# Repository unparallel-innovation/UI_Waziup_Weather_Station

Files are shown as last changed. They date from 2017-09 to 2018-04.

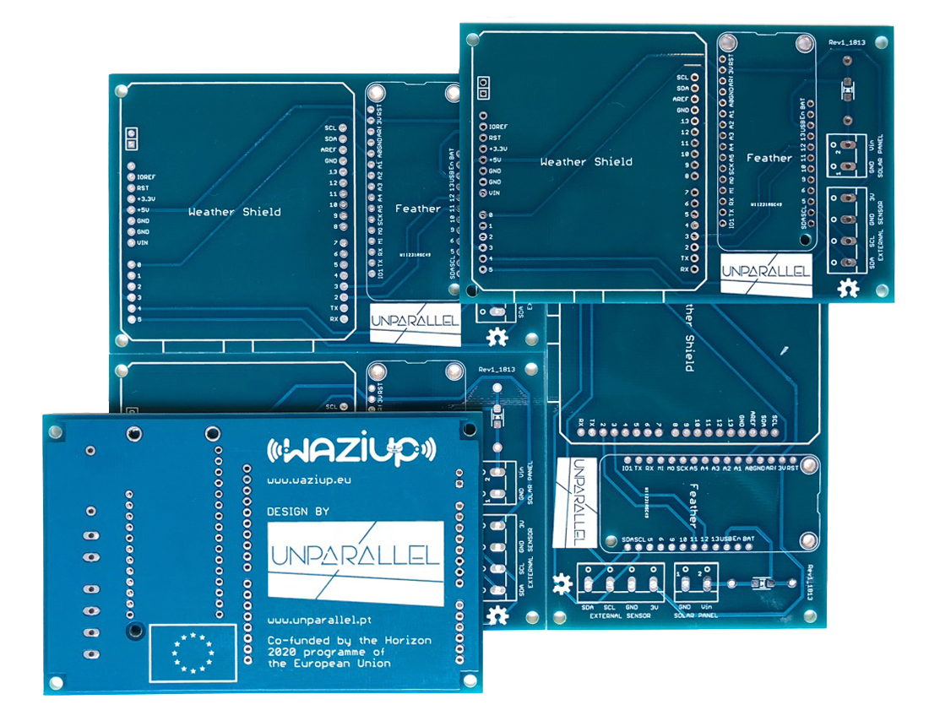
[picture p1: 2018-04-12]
Proto_Feather_with_Weather/proto_Feather_with_Weather_0v20.png

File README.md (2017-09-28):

# LoRa Weather Station for Waziup project - by UNPARALLEL Innovation, Lda

This repository provide all information related to the LoRa Weather Station. 
This Weather Station uses LoRa communication technology. It describes the creation of a vigilant weather supervision, composed by multi-tech sensors as part of the IoT sensor node with LoRa network integration. This work was done in the context of Waziup Research Project, which has received funding from the European Union’s H2020 Programme for research, technological development and demonstration under grant agreement No 687607.

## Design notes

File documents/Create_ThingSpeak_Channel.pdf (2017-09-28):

## Create the ThingSpeak channel

To be able to send weather data from the LoRa Weather Station to a ThingSpeak channel it is need to take a few steps.

1) First of all login on the platform¹ with the following email and password:

Email: noitedoinvestigador@unparallel.pt
Password: NoiteInvestigador2017

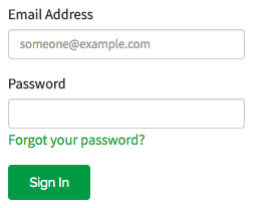
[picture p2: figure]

Figure 1 – Login on the ThingSpeak platform.

After insert, the email and the password click in the green “Sign In” button.

2) After sign in, go on the top bar “Channels”, “My channels” and then click in “New Channel” like in the following figure

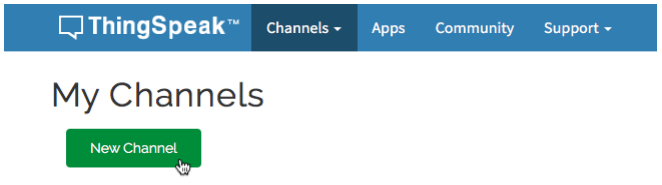
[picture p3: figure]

Figure 2 – Create a new channel in ThingSpeak.

1 https://thingspeak.com/

3) Fill “Name” and “Description” boxes with information about the new ThingSpeak.

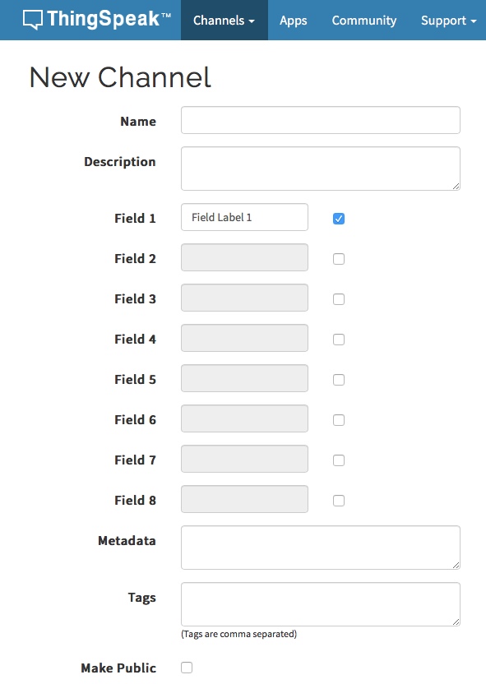
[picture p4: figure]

Figure 3 - Information about the new ThingSpeak channel.

4) Check the field boxes to be able to give the following names:
- Filed 1: “Temperature”
- Field 2: ”Humidity”
- Field 3: “Pressure”
- Field 4: “Wind Direction”
- Field 5: “Wind Speed”
- Filed 6: “Wind Gust”
- Field 7: “Amount of Rain”
- Filed 8: “Battery Voltage”
5) Check the “Make Public” button.

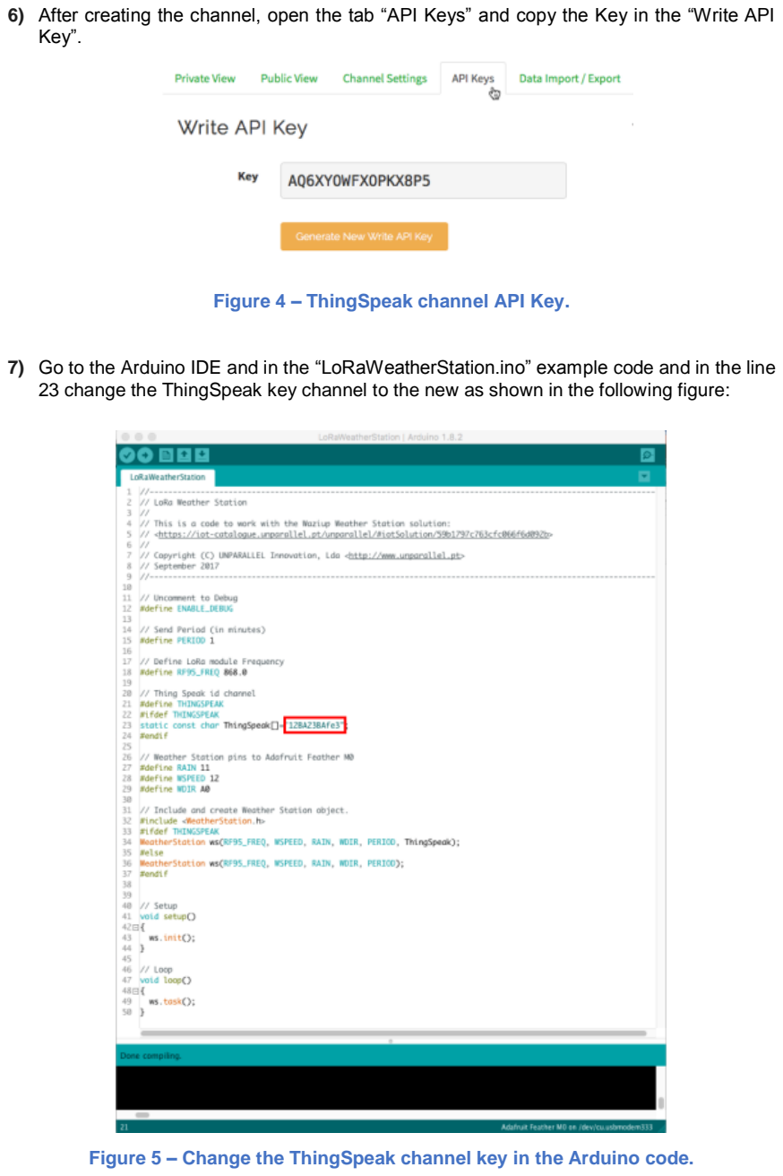
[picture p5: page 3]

6) After creating the channel, open the tab “API Keys” and copy the Key in the “Write API Key”.

Figure 4 – ThingSpeak channel API Key.

7) Go to the Arduino IDE and in the “LoRaWeatherStation.ino” example code and in the line 23 change the ThingSpeak key channel to the new as shown in the following figure:

Figure 5 – Change the ThingSpeak channel key in the Arduino code.

8) The following examples shows the result, for a short period of time, from Weather Station in the ThingSpeak Cloud platform.

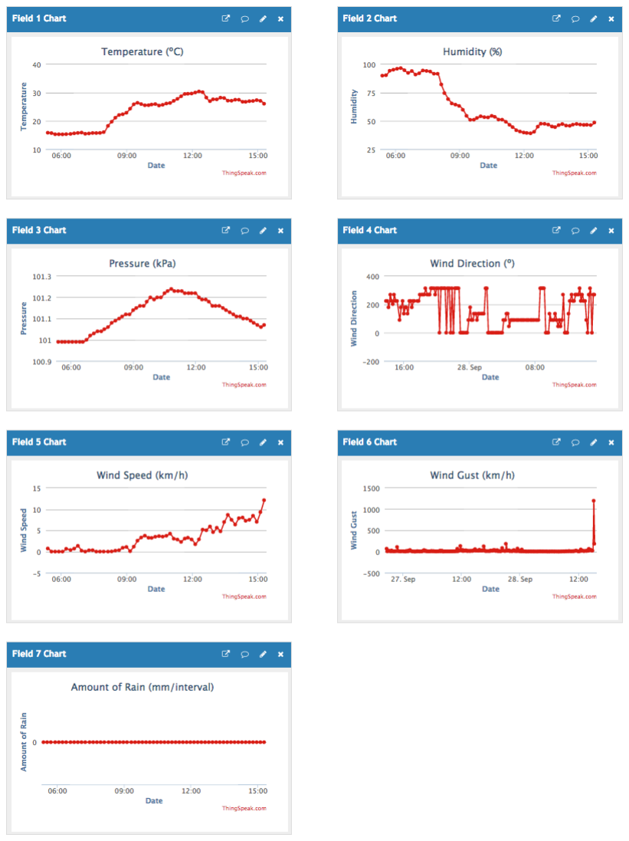
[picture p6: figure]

Figure 6 - Represented the ThingSpeak Cloud platform.

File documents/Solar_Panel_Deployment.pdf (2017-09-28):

# Solar Panel Deployment

Simple guide to deploy a Solar Panel.

Responsible Editor: Unparallel Innovation, Lda Contributors:
Document Reference: | Solar Panel Deployment
Distribution: | Public
Version: | 1.0
Date: | 28 September 2017

Table of Contents

List of Figures

# 1 . Deployment

Solar Panels are devices that consist in a set of solar cells capable to convert light into energy and if the amount of light that reach a cell increase, more energy will be produced and will increase the solar panel efficiency.

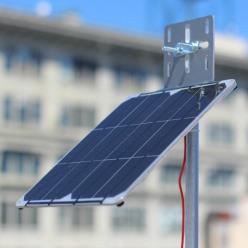
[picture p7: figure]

Figure 1 - Example of a Solar Panel deployment.

In order to have maximum possible efficiency, the panel must be pointed directly at the light source. The panel positioning is the most important because if implemented with wrong direction and slope will affect the solar panel efficiency.

For each location is extremely necessary and is a good policy to set a direction and slope that receive the maximum incident of sunlight to increase the efficiency of the solar panel under ideal conditions. Protecting them from excessive exposure to water/vapors is also necessary because this can oxidize the surface of the solar panel and reduce its performance.

The position of the Sun relative to the Earth has determine the ideal angle. It is recommended that the solar panel be deployed to pointed to “South” if the intended location is in the Northern Hemisphere or to pointed to “North” if the location is in the Southern Hemisphere as shown in the Figure 2.

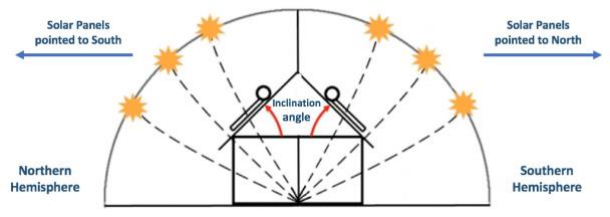
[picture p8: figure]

Figure 2 - Direction to pointed Solar Panels for location in Northern/Southern hemisphere.

However, it is necessary to analyze the location because there may be shadows and obstacles that reduce the efficiency of the solar panel. In a careful deployment, is necessary to specify the worst conditions and is recommended to use an external source of information to aid in the implementation. The selected location was Lisbon which is located in the Northern hemisphere. In this case the solar panel needs to be pointed to South as represented in the Figure 3.

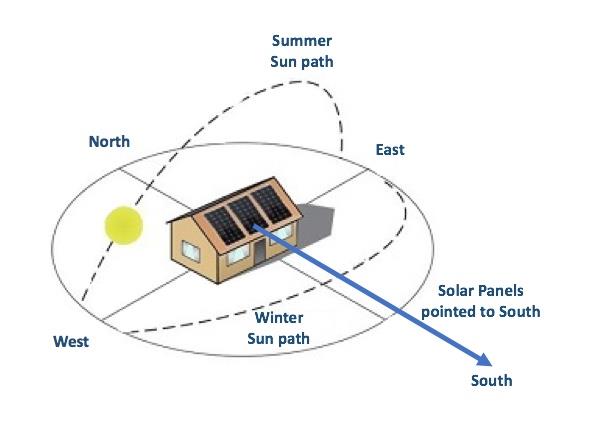
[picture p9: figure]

Figure 3 - Solar Panel deployment pointed to South.

Using a website¹
to simulate the recommended slopes, was possible to find the ideal angles per month to have maximum efficiency of the solar panel. To optimize the solar panels, is necessary adjust the slope to the values that are recommended for each of the months as shown in the Figure 4.

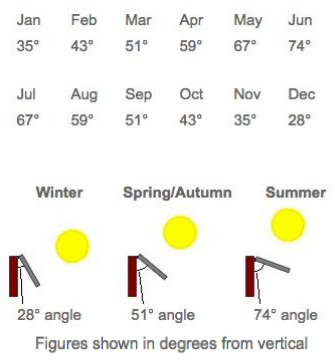
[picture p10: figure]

Figure 4 - Optimum Inclination of Solar Panels by Month and seasons.

It is also possible to adjust for the three recommended seasons of the year. In Lisbon, the recommended values for Winter is a slope of 28º, for Spring and Autumn an inclination of 51º and in the Summer the slope of 71º.

With this platform is possible to get the recommended values but other sources with different types of information can also be used to optimize the solar panels.

1 http://www.solarelectricityhandbook.com/solar-angle-calculator.aspx

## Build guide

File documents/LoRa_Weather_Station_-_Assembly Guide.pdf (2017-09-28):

WAZIUP: Co-funded by the Horizon 2020 Framework Programme of the European Union

www.waziup.eu

# Open Innovation Platform for IoT-Big data in Sub-Sahara Africa

# Grant Agreement Nº 687607

## Agriculture MVP Waziup Weather Station – Assembly Guide

Responsible Editor: Unparallel Innovation, Lda

Contributors:

Document Reference: | LoRa Weather Station - Assembly Guide
Distribution: | Public
Version: | 1.0
Date: | 28 September 2017

Project Nº 687607

TABLE OF CONTENTS

LIST OF FIGURES

Figure 1 – Components chosen | 6
Figure 2 – Female Header pins in Feather | 7
Figure 3 – uFL SMT Antenna Connector in Feather | 7
Figure 4 – Female header pins and RJ11 connectors in Weather Shield | 8
Figure 5 – Connect the 868MHz Antenna in Feather | 8
Figure 6 – Different SMA and RP-SMA connectors | 9
Figure 7 – Weather Shield power connection | 10
Figure 8 – Weather Shield internal sensors pin connection | 11

Figure 9 – Power and internal sensors connection between Feather and Weather Shield. ..11

Figure 10 – Pin Connection between Feather, External sensor and Weather Shield | 12
Figure 11 – Weather Meters and respective Rain and Wind connections | 13
Figure 12 – Connect the Battery in the Feather | 13
Figure 13 – Correct Diode connection | 14
Figure 14 – Solar Panel connection | 14
Figure 15 – Add Adafruit Boards to Arduino IDE | 15
Figure 16 – Install Adafruit Boards in Arduino IDE | 16
Figure 17 – Install Weather Station library by the "Add. ZIP Library" | 17
Figure 18 – Define the USB port | 17
Figure 19 – Upload the software | 18
Figure 20 – Place Weather Station in a box | 19
Figure 21 – Place external sensor outside the box | 19
Figure 22 – LoRa Weather Station prototype | 20

## LIST OF TABLES

Table 1 – Pin Connection to power the Weather Shield | 9
Table 2 – Weather Shield internal sensors pin connection | 10
Table 3 – Pin Connection between Feather, External sensor and Weather Shield | 12

## 1. INTRODUCTION

This document describe the development of a Waziup Weather Station using low-cost hardware that together will communicates with Waziup LoRa Gateway. In order to develop this solution, multi-technology sensors were used as part of the IoT sensor node with LoRa network integration.

The challenge was to develop an easy-to-deploy solution capable of acquire data from the surrounding area and then making it available to the Waziup Cloud Platform. This solution uses a several components that are easily bought on the market and can be potentially replaced by equivalent models.

This work was done in the context of Waziup Research Project, which has received funding from the European Union’s H2020 Programme for research, technological development and demonstration under grant agreement No 687607.

## 2. COMPONENTS

The objective is to develop a low-cost and sustainable solution capable of reading real-time data typical of a Weather Station, using different sensors, and capable of communicating via LoRa.

The components chosen was:

- Adafruit Feather M0 with RFM95 LoRa Radio
- Sparkfun Weather Shield
- Weather Meters
- 4,5 dBi 868-900 SMAM-RP Antenna
- uFL SMT Antenna Connector
- RP-SMA to uFL/u.FL/IPX/IPEX RF Adapter Cable
- 2x RJ11 6-Pin Connector
- 36-pin 0.1" Female header - pack of 5
- Adafruit AM2315 Sensor
- 1.5W Solar Panel 81x137
- Lithium-Ion Battery - 3.7v 2200mAh
- Schottky Rectifying Diode

The use of all this material allowed the development of the "LoRa Weather Station" solution that cost less than 200€ and is available on the IoT-Catalogue platform through the following link¹

In the following Figure 1 are represented the respective materials mentioned above.

1 https://iot-catalogue.unparallel.pt/unparallel/#iotSolution/59b1797c763cfc066f6d092b

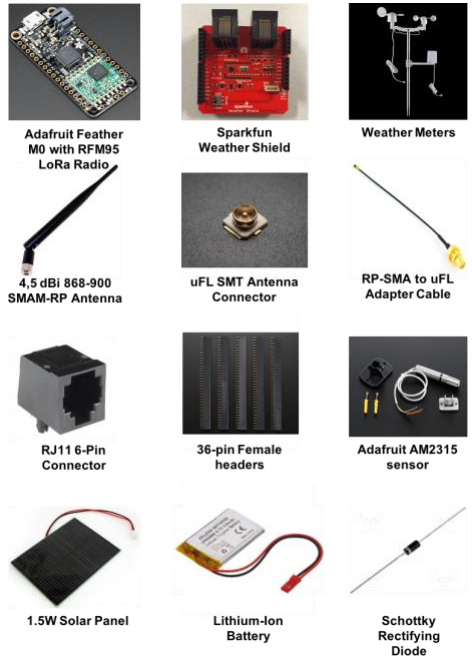
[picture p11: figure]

Figure 1 – Components chosen.

The next sections provide a step-by-step tutorial on how to build the LoRa Weather Station in order to collect data and send them to the gateway.

First, it is necessary to assembling the chosen components, and then upload the software. All the information used for this Weather Station is open source and hosted in the Unparallel Innovation GitHub repository²

2 https://github.com/unparallel-innovation/UI_Waziup_Weather_Station

## 3. ASSEMBLY WEATHER STATION

Before connecting the cables between the components, it is necessary to perform delicate but simple solder task. Is recommended to train a little by following a guide as Adafruit³

## 3.1. Solder Components

### 3.1.1. Adafruit Feather

The Adafruit Feather M0 comes with fully assembled and tested radio but is necessary solder the female header pins in Feather by following the Adafruit guide⁴
. In the following Figure 2 can be seen the Adafruit Feather M0 after solder the female header pins.

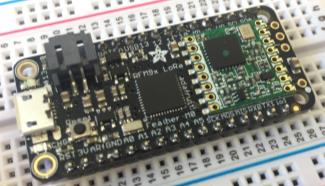
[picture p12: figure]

Figure 2 – Female Header pins in Feather.

### 3.1.2. uFL Antenna Connector in Feather

To use an 865MHz Antenna, it is required to solder the “uFL SMT Antenna Connector” in the Adafruit Feather M0 by following the steps in the Adafruit guide⁵

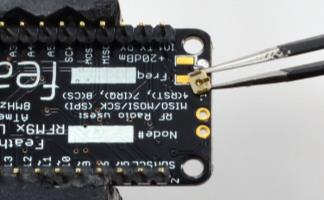
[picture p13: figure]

Figure 3 – uFL SMT Antenna Connector in Feather.

3 https://learn.adafruit.com/adafruit-guide-excellent-soldering
4 https://learn.adafruit.com/adafruit-feather-m0-radio-with-lora-radio-module/assembly
5 https://learn.adafruit.com/adafruit-feather-m0-radio-with-lora-radio-module/antenna-options

### 3.1.3. Sparkfun Weather Shield

The Sparkfun Weather Shield does not come with the female header pins or the RJ11 6-Pin Connector included. As such it is necessary to order these components as well. Start by solder the female header pins in the Weather Sheild by following the suggested steps in the official Sparkfun guide⁶

### 3.1.4. RJ11 connectors in Weather Shield

To acquire rain and wind data from the Weather Meters sensor kit, it is necessary to solder the two RJ11 connectors in the Sparkfun Weather Shield. The Figure 4 shows the Sparkfun Weather Shield after solder the female header pins and the two RJ11 connectors.

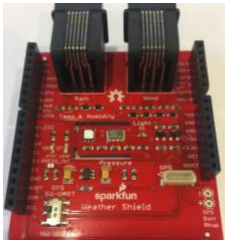
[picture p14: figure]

Figure 4 – Female header pins and RJ11 connectors in Weather Shield.

## 3.2. Boards Connection

### 3.2.1. Connect Antenna

Once soldered the “uFL SMT Antenna Connector”, can be connected the 868MHZ Antenna in the Adafruit Feather M0. As such, it is necessary to screw the 868MHZ Antenna into the “RP-SMA to uFL Adapter Cable" to be able to connect to the “uFL SMT Antenna Connector” soldered in Adafruit Feather M0.

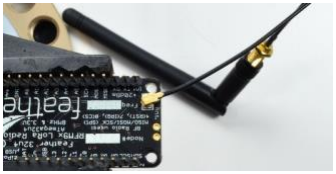
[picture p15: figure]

Figure 5 – Connect the 868MHz Antenna in Feather.

6 https://learn.sparkfun.com/tutorials/arduino-shields/installing-headers-assembly

Note that there are also products in the market that have the 868MHZ Antenna and the RP-SMA to uFL Adapter together.

It is necessary that the type of connection between the “uFL SMT Connector Adapter” and the Antenna must have the same type. If it does not happen, although it is possible to screw, will not be possible to make the communication.

Therefore, only "SMA Male" can be connected with "SMA Female" and "RP-SMA Male" with "RP-SMA Female". These different types of connectors are shown in the following Figure 6.

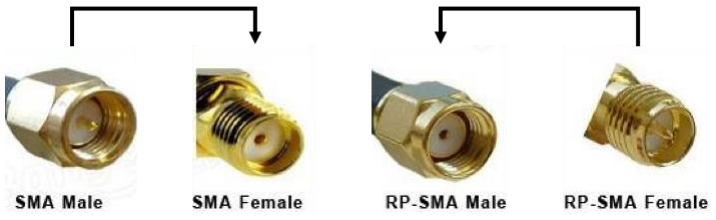
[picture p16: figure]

Figure 6 – Different SMA and RP-SMA connectors.

### 3.2.2. Power the Weather Shield

It is recommended to use a breadboard and cables with different colours when connect the circuits. To power the Weather Shield, use the Feather “3V” pin and make sure to connect in the Weather Shield “3.3V” pin and not in the “+3.3V”. Also connect the Feather “3V” pin in the Weather Shield “+5V” pin.

It is also necessary connect the Feather “GND” pin to the Weather Shield “GND” pin. The following Table 1 and Figure 7 respectively presents and shows the power connection using the breadboard as a bus between the Adafruit Feather M0 and the Sparkfun Weather Shield.

Table 1 – Pin Connection to power the Weather Shield.

Adafruit Feather | Sparkfun Weather Shield
GND | GND
3V | (+5V) and (3.3V)

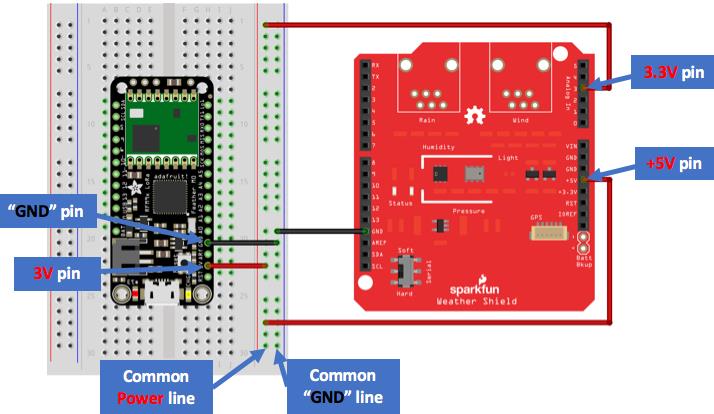
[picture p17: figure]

Figure 7 – Weather Shield power connection.

3.2.3. Connect Weather Shield sensors.

The Sparkfun Weather Shield already has built-in sensors that need to be connected to the Adafruit Feather M0. Theses connection are established in the Table 2 and is shown in Figure 8

First it is necessary connect the Feather “SDA” pin to the Weather Shield “SDA (4)” pin and the Feather “SCL” pin to the Weather Shield “SCL (5)” pin.

The Wind Direction connection is shown through the green cable that connect the Feather “A0” pin to the Weather Shield “WDir (0)” pin.

The Rain pin must be connected as shown in figure through the orange cable by connect the Feather “11” pin to the Weather Shield “RAIN” pin.

To the Wind Speed, connect the Feather ”12” pin to the Weather Shield “WSpd (3)” as shown through the blue cable.

Table 2 – Weather Shield internal sensors pin connection.

Adafruit Feather | Sparkfun Weather Shield
SDA | SDA(4)
SCL (white cable) | SCL(5) (white cable)
A0 | WDir (0)
11 | RAIN (2)
12 | WSpd (3)

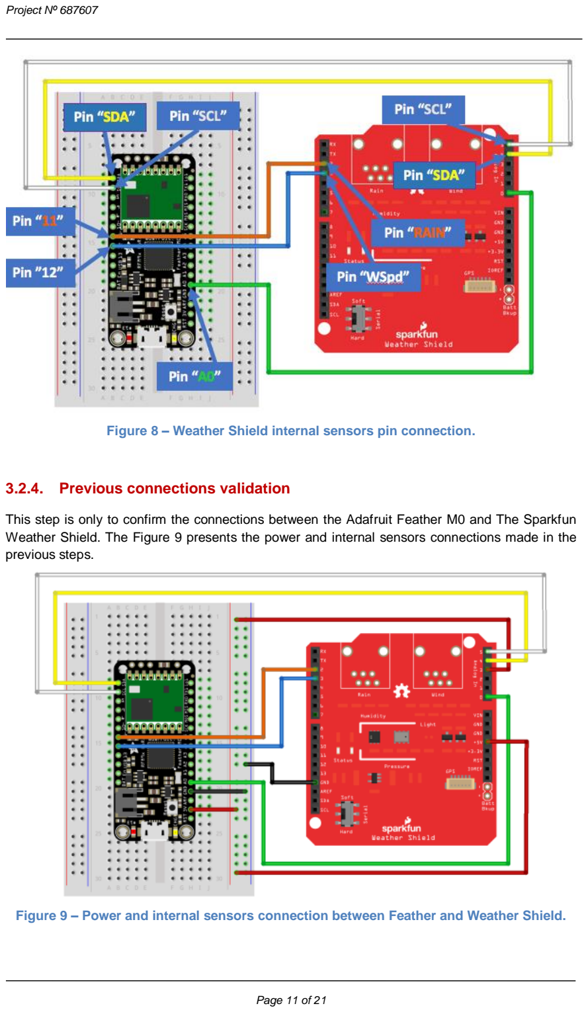
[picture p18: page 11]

Figure 8 – Weather Shield internal sensors pin connection.

### 3.2.4. Previous connections validation

This step is only to confirm the connections between the Adafruit Feather M0 and The Sparkfun Weather Shield. The Figure 9 presents the power and internal sensors connections made in the previous steps.

Figure 9 – Power and internal sensors connection between Feather and Weather Shield.

3.3. Components connection.
3.3.1. Connect External sensor.

The Table 3 established the connection between the Adafruit Feather M0, the AM2315 Temperature and Humidity external sensor and the Sparkfun Weather Shield. The following Figure 10 presents the Table 3 established connection.

The Weather Shield has one more set of “SDA” and “SCL" pins (the last two pins on the left side) that can be used to connect the external sensor yellow cable to the Weather Shield “SDA” pin and the external sensor white cable to the Weather Shield “SCL” pin. Also connect the external sensor red cable “VCC” to the common power of the breadboard and the external sensor black cable “GND” to the common "GND" of the breadboard.

Table 3 – Pin Connection between Feather, External sensor and Weather Shield.

Breadboard | Sparkfun Weather Shield | AM2315 sensor
GND | - | Black cable
3V | - | Red cable
- | SDA(4) | Yellow cable
- | SCL(5) | White cable

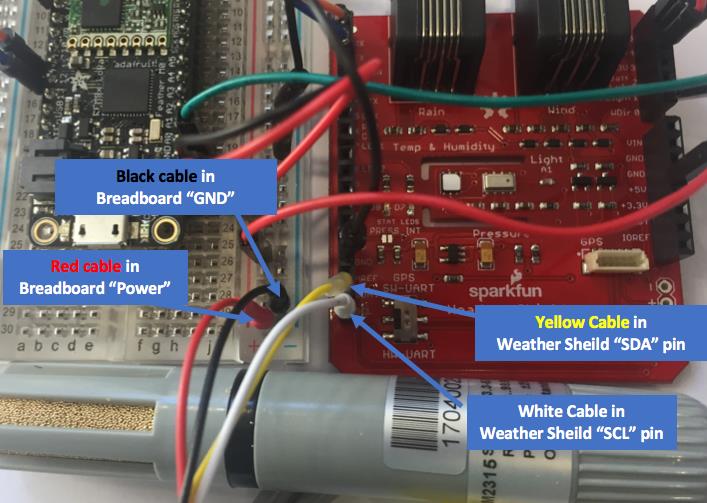
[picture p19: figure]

Figure 10 – Pin Connection between Feather, External sensor and Weather Shield.

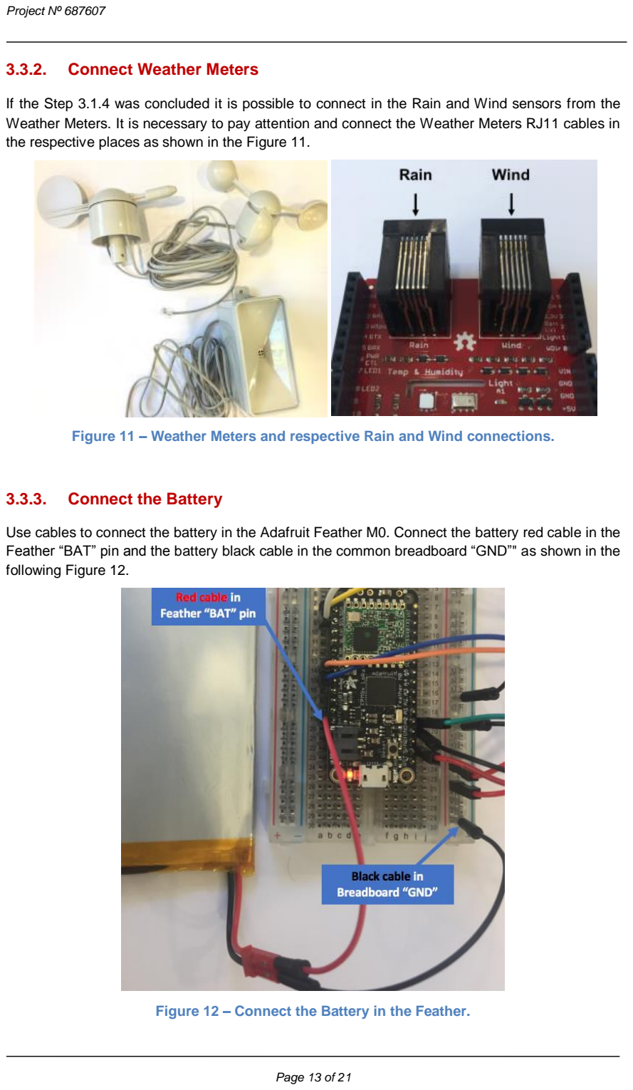
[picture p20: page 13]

### 3.3.2. Connect Weather Meters

If the Step 3.1.4 was concluded it is possible to connect in the Rain and Wind sensors from the Weather Meters. It is necessary to pay attention and connect the Weather Meters RJ11 cables in the respective places as shown in the Figure 11.

Figure 11 – Weather Meters and respective Rain and Wind connections.

### 3.3.3. Connect the Battery

Use cables to connect the battery in the Adafruit Feather M0. Connect the battery red cable in the Feather “BAT” pin and the battery black cable in the common breadboard “GND”" as shown in the following Figure 12.

Figure 12 – Connect the Battery in the Feather.

### 3.3.4. Connect the Solar Panel

The Adafruit Feather M0 comes with an integrated charging circuit which allows to charge the battery using an external power source. To use a Solar Panel to charge the battery it is also necessary to use a Schottky Diode that allows that the current to go in the right direction and not to the Solar Panel.

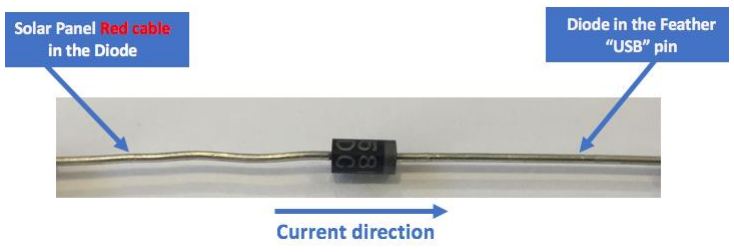
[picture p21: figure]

Figure 13 – Correct Diode connection.

As represented in the Figure 14 connect the Solar Panel red cable to the Schottky diode and from the diode to the Feather “USB” pin using the breadboard as a bus. Also connect the Solar Panel black cable “GND” to the common breadboard “GND”.

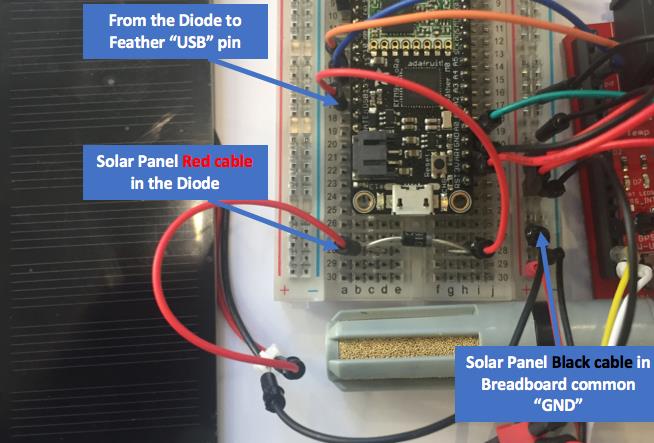
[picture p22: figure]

Figure 14 – Solar Panel connection.

## 4. UPLOAD SOFTWARE

## 4.1. Download & Install Arduino IDE

First, it is necessary to download the Arduino IDE 1.6.6 or later. Go to the Arduino website⁷ ,
select “Software” and choose the compatible version with the operating system that is being.

Once the download is complete, the Arduino IDE can be installed by following the suggested steps in the official operating system installation guide⁸

## 4.2. Add Adafruit Boards to Arduino IDE

After completed the previous steps it is necessary go to “Arduino”, “Preferences” and include the link for Adafruit boards in the "Additional Boards Manager URLs" as shown in the Figure 15.

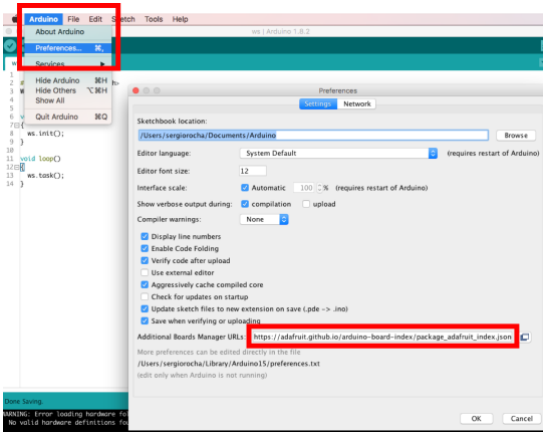
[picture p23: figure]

Figure 15 – Add Adafruit Boards to Arduino IDE.

To get the link for the Adafruit boards and conclude this task it is recommended to follow the steps in the official Adafruit guide⁹

7 https://www.arduino.cc/en/Main/Software
8 https://www.arduino.cc/en/Guide/HomePage

9
https://learn.adafruit.com/adafruit-feather-m0-radio-with-lora-radio-module/setup

4.3. Install Adafruit Boards in Arduino IDE.

Once added the Adafruit Boards in the Arduino IDE, it is necessary go to “Tools”, “Board” and access the “Board Manager” to install the required Adafruit Board. To install correctly the Adafruit boards it is recommended to follow the steps in the official Adafruit guide for the Adafruit Feather M0¹⁰ board.

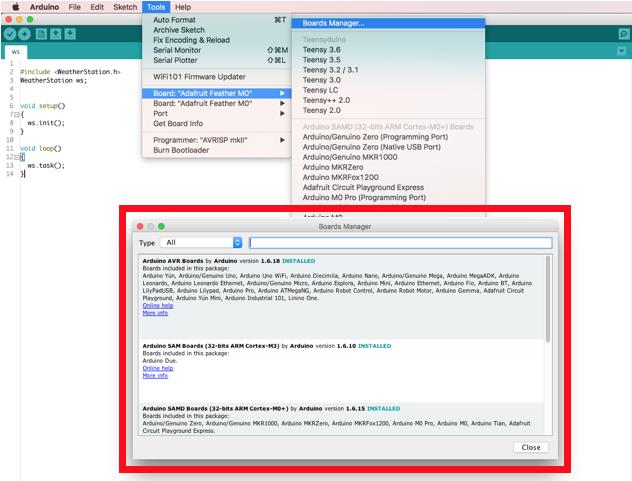
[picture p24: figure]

Figure 16 – Install Adafruit Boards in Arduino IDE.

4.4. Download Weather Station library.

It is necessary to acquire the Weather Station library presents in the Unparallel Innovation Github¹¹ that includes all necessary control functions and a set of other resources that allow the correct operation of the LoRa Weather Station. To do that click on “Clone or download” green button located in the right side from GitHub website and choose “Download Zip” option to download the “UI_Waziup_Weather_Station-master.zip” file.

## 4.5. Install Weather Station library in Arduino IDE

Once | completed | the | previous | step | is | necessary | include | the | downloaded
“UI_Waziup_Weather_Station.zip” file in the Arduino IDE. To do that go to “Sketch”, “Include Library” and click in the “Add .ZIP Library” option. Will appear a window where need to be added the zip file.

10 https://learn.adafruit.com/adafruit-feather-m0-radio-with-lora-radio-module/using-with-arduino-ide 11 https://github.com/unparallel-innovation/UI_Waziup_Weather_Station

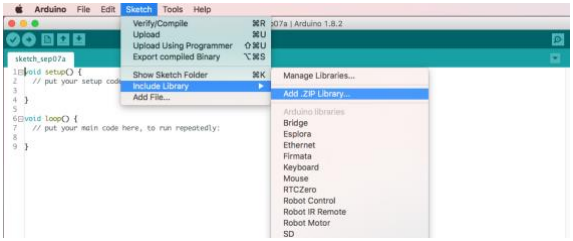
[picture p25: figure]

Figure 17 – Install Weather Station library by the "Add. ZIP Library".

4.6. Open Weather Station example code.

After conclude with success the previous step it is possible to open the Weather Station example code. To do that go to “File”, “Examples”, “UI_Waziup_Weather_Station” and click in the “LoRaWeatherStation”.

This code, is the latest firmware tested from the LoRa Weather Station and include all the Weather Station configurations.

## 4.7. Choose Board and USB Port in Arduino IDE

After connect the micro-USB cable from the computer to the Feather, it is necessary choose the correct Adafruit Feather Board and the USB port in the Arduino IDE. To do that go to “Tools”, “Board” and click in the “Adafruit Feather M0” and go to Tools”, “Port” and click in the “Adafruit Feather M0” too.

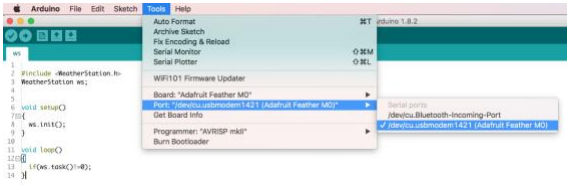
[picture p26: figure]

Figure 18 – Define the USB port.

## 4.8. Upload the Weather Station software

The Weather Station already has some configuration parameters defined by default such as the period time in minutes between messages and the ThingSpeak identification channel that can be changed.

To upload the software in the Adafruit Feather M0 just need to click in the “Upload” button presented in the upper left side of the following Figure 19.

After concluding the upload with success, a message will appear in the lower left side. To open the Arduino Serial Monitor and visualize the LoRa Weather Station workflow click in upper right side button.

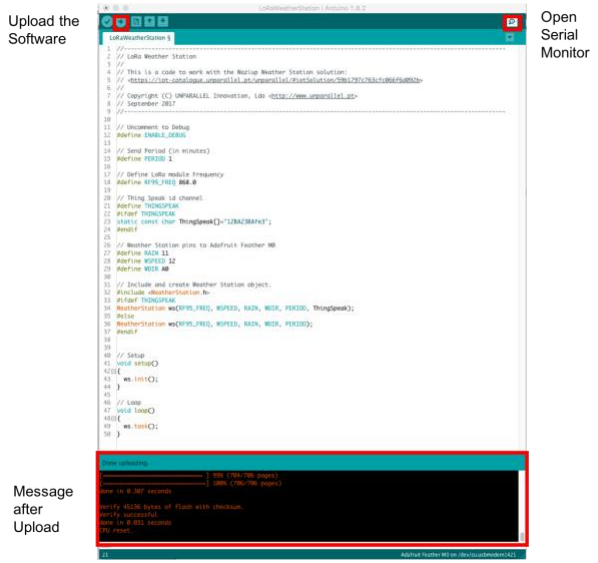
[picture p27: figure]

Figure 19 – Upload the software.

## 5. DEPLOYMENT WEATHER STATION

## 5.1. Assembly Weather Station in a Box

Once the previous steps have been completed, it will be necessary to place the assembly Weather Station inside a box to place easily in the desired location. The following Figure 20 show, as an example, the Weather Station in a box that not need to be the same. Pay attention to the material that the box is made. To place the Weather Station in locations under rain, it is convenient to use a waterproof box.

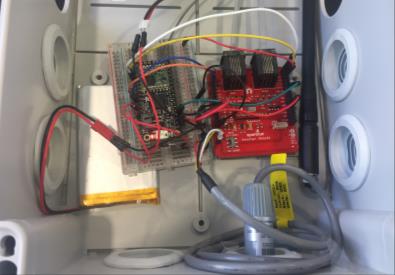
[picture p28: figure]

Figure 20 – Place Weather Station in a box.

Place the components with some organization because will be easier in the future to change one component or access the microprocessor to re-upload the software. To place the components, use a contact material such as hot glue to ensures that the hardware is in the correct places and no cable connection is lost if, for some reason, a strong oscillation occurs in the box.

## 5.2. External Sensor outside the box

Make sure that the temperature and humidity external sensor is slightly out of the box, as shown in the box of Figure 21, and preferably in a shadow location without sun.

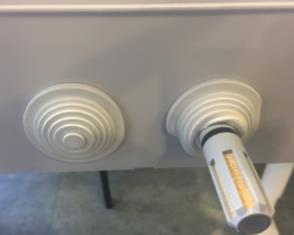
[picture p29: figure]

Figure 21 – Place external sensor outside the box.

## 5.3. Assembly Weather Meters sensors

The Weather Meters come with material components, to allow their assembly in an auxiliary structure. These materials together allow to build a structure to easily place the sensors (rain, wind speed and wind direction).

Once assembled this structure can be placed in the desired location. To mount it is recommended to perform the suggested steps in the guide provided by SparkFun¹²

## 5.4. Solar Panel outside the box

It is necessary to place the Solar Panel outside the box in a place where it is possible to guarantee the conditions of implementation. To realize and ensure a correct Solar Panel implementation it is recommended to consult the "Solar Panel Deployment" document that is available in folder “documents” in the Unparallel Innovation GitHub repository¹³

The hole created for the external sensor can be used to route the Solar Panel cables as well as the RJ11 Rain and Wind sensor cables.

Completed these steps the LoRa Weather Station shown in the Figure 22 is ready to receive the measurements and send the information to the LoRa gateway.

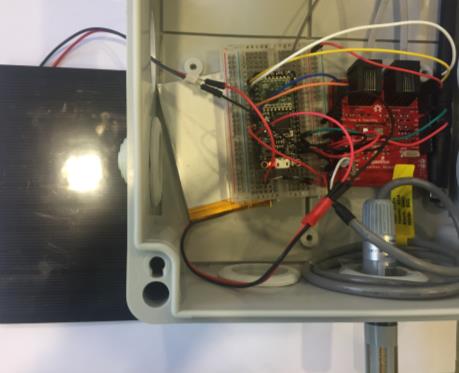
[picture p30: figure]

Figure 22 – LoRa Weather Station prototype.

12 https://learn.sparkfun.com/tutorials/weather-meter-hookup-guide
13 https://github.com/unparallel-innovation/UI_Waziup_Weather_Station

### ACKNOWLEDGEMENT

This document has been produced in the context of the H2020 Waziup project. The Waziup project consortium would like to acknowledge that the research leading to these results has received funding from the European Union’s H2020 Research and Innovation Programme under the Grant Agreement H2020-ICT-687670.

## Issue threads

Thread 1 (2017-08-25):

Variable cannot be cleared

miguelcostaUI, 2017-08-25:
https://github.com/unparallel-innovation/UI_Waziup_Weather_Station/blob/a1a46c5d0b9567f99c8d8469a469c97f620dc523/WAZIUP_Weather_Station_Client/WAZIUP_Weather_Station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

This variable cannot be cleared. It introduces an error in the calculation of the period used for wind gust calculation.

Closed 2017-09-04.

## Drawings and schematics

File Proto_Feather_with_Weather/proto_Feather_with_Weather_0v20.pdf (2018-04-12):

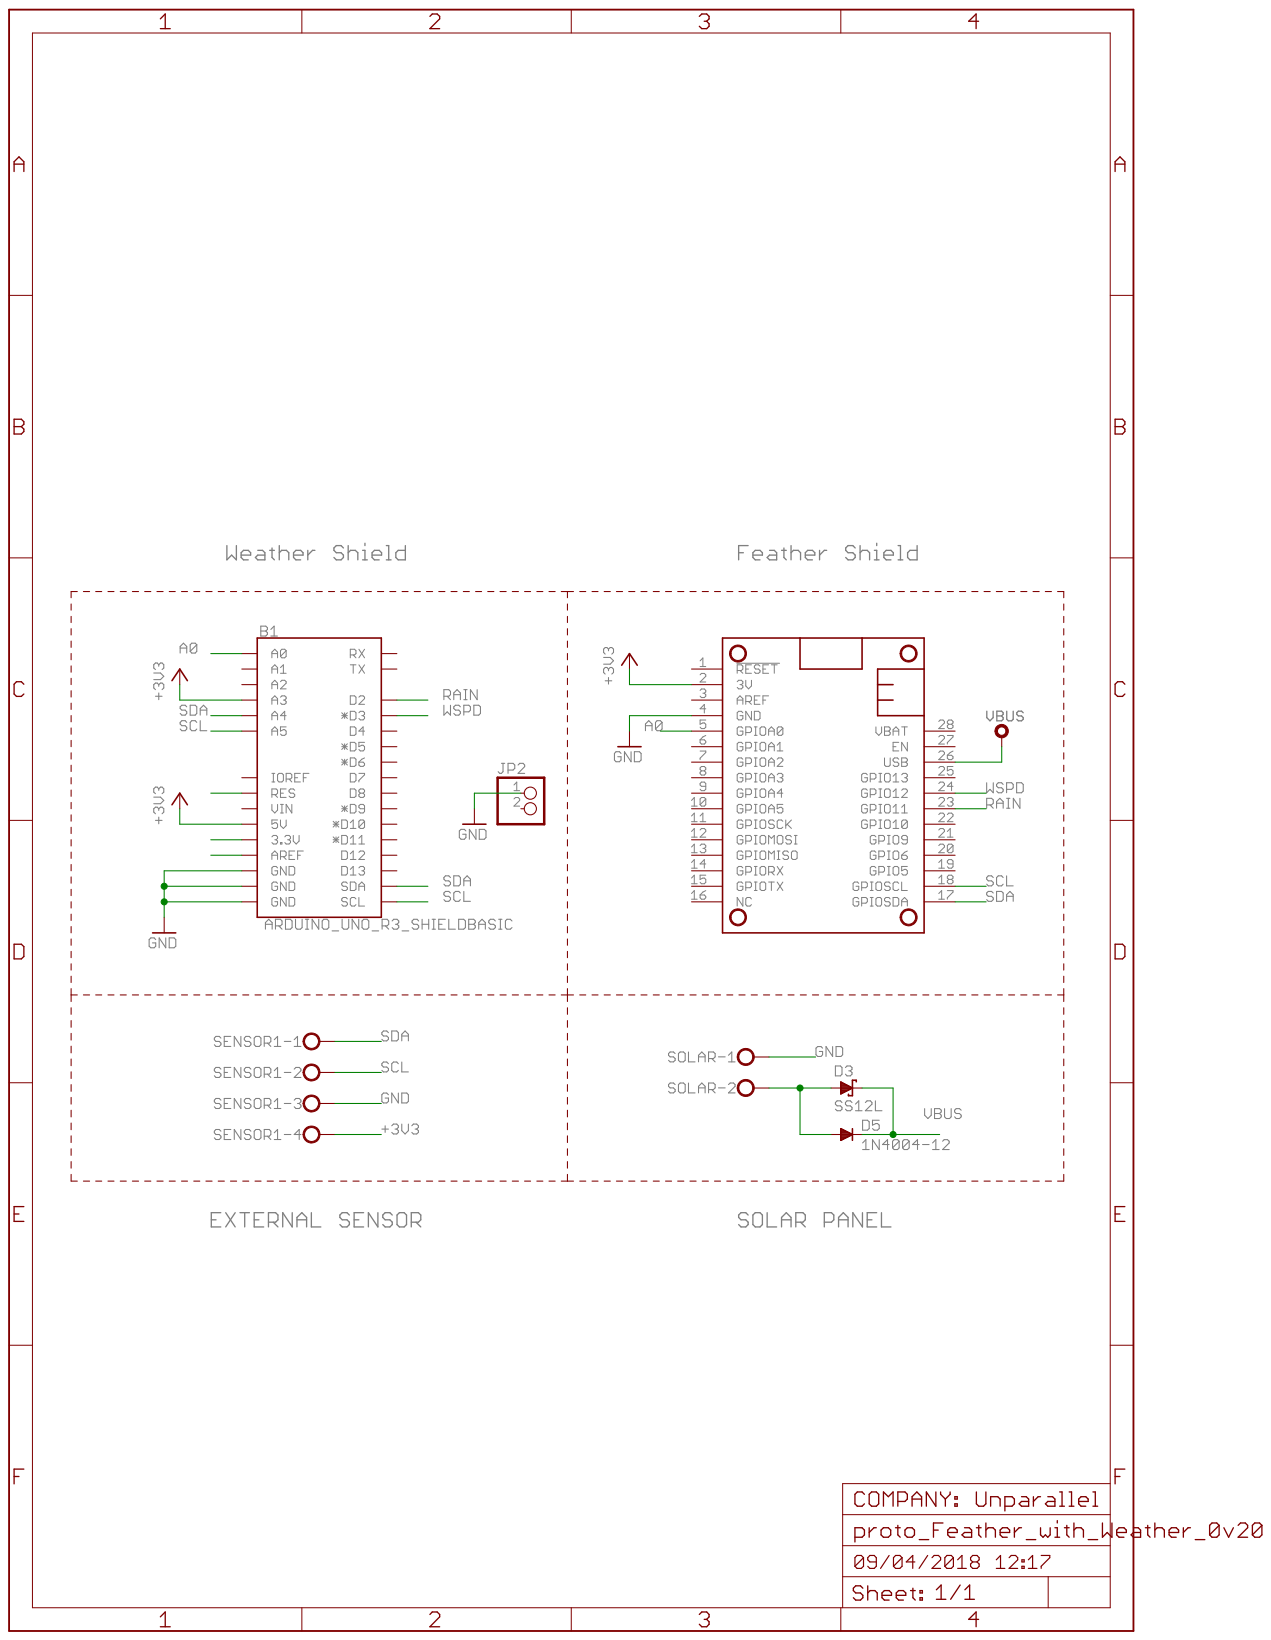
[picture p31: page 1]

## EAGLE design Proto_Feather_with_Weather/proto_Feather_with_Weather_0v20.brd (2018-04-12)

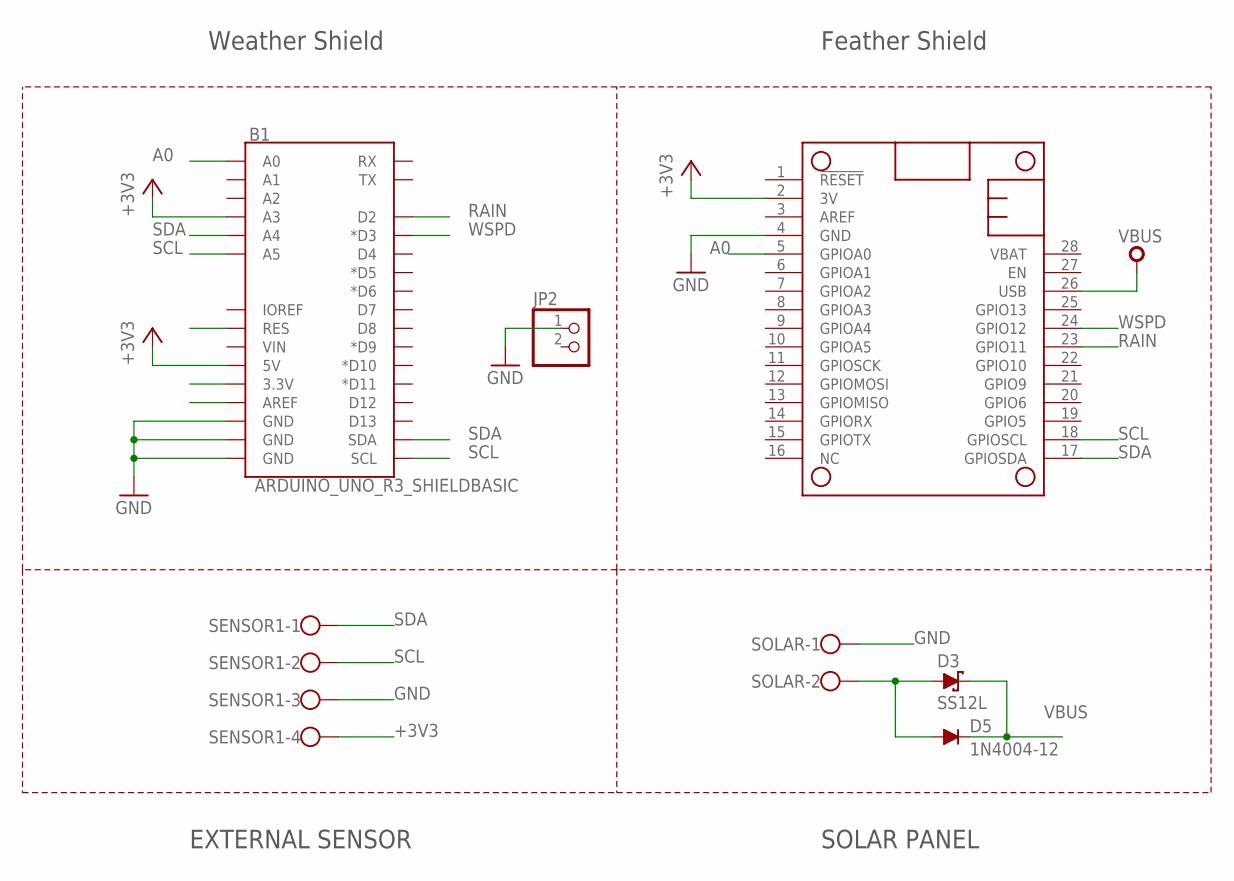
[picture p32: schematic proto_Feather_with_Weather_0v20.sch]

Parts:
B1: ARDUINO_UNO_R3_SHIELDBASIC; UNO_R3_SHIELD
D3: SS12L; SUB_SMA_PROTO
D5: 1N4004-12; DO41-12
JP2: PINHD-1X2; 1X02
MS2: FEATHERWING_NODIM; FEATHERWING_DIM
SENSOR1: W237-4
SOLAR: W237-102

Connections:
+3V3: B1.5V, B1.A3, MS2.2 (3V), SENSOR1.4
A0: B1.A0, MS2.5 (GPIOA0)
GND: B1.GND@0 (GND), B1.GND@1 (GND), B1.GND@2 (GND), JP2.1, MS2.4 (GND), SENSOR1.3, SOLAR.1
unnamed: D3.A, D5.A, SOLAR.2
RAIN: B1.D2, MS2.23 (GPIO11)
SCL: B1.A5, B1.SCL, MS2.18 (GPIOSCL), SENSOR1.2
SDA: B1.A4, B1.SDA, MS2.17 (GPIOSDA), SENSOR1.1
VBUS: D3.C, D5.C, MS2.26 (USB)
WSPD: B1.D3 (*D3), MS2.24 (GPIO12)

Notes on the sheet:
Weather Shield
Feather Shield
EXTERNAL SENSOR
SOLAR PANEL

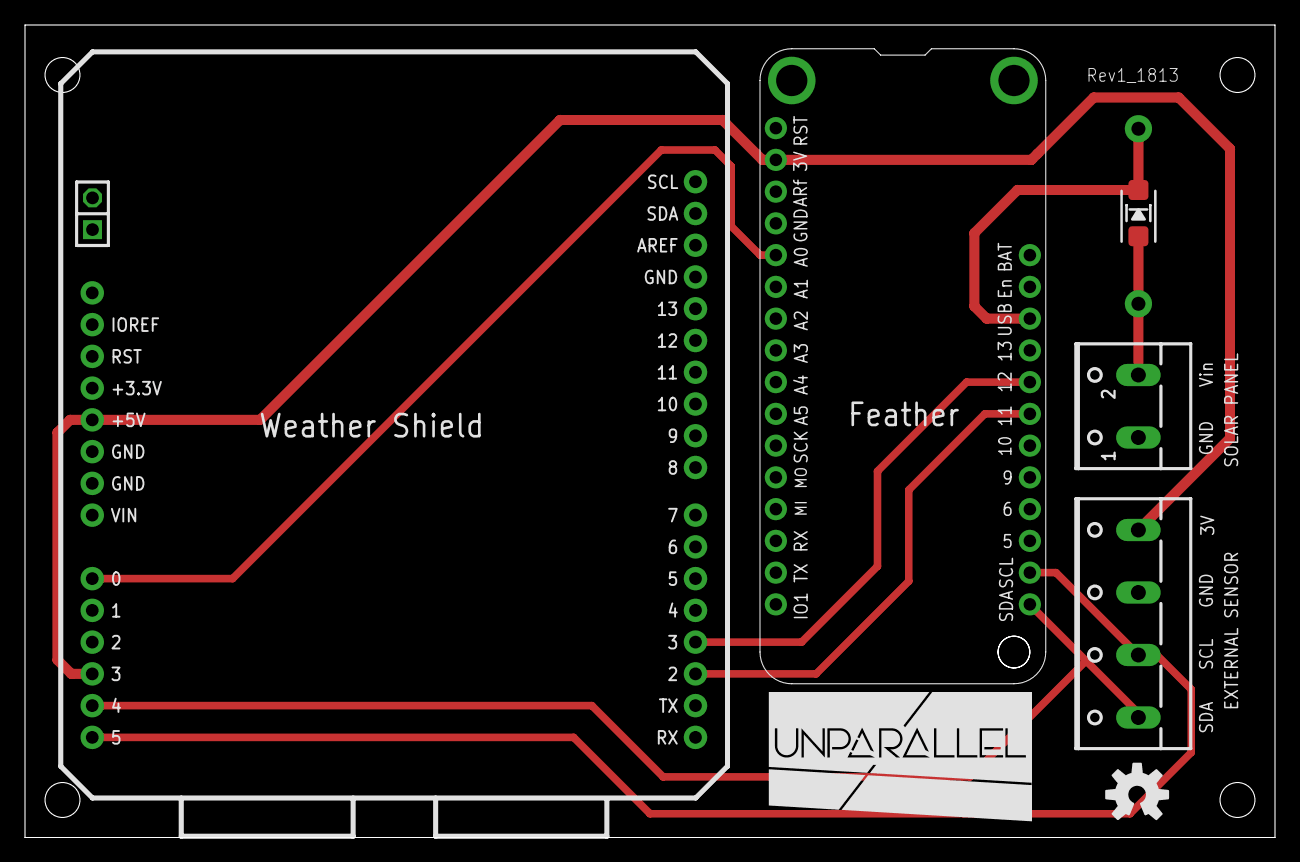
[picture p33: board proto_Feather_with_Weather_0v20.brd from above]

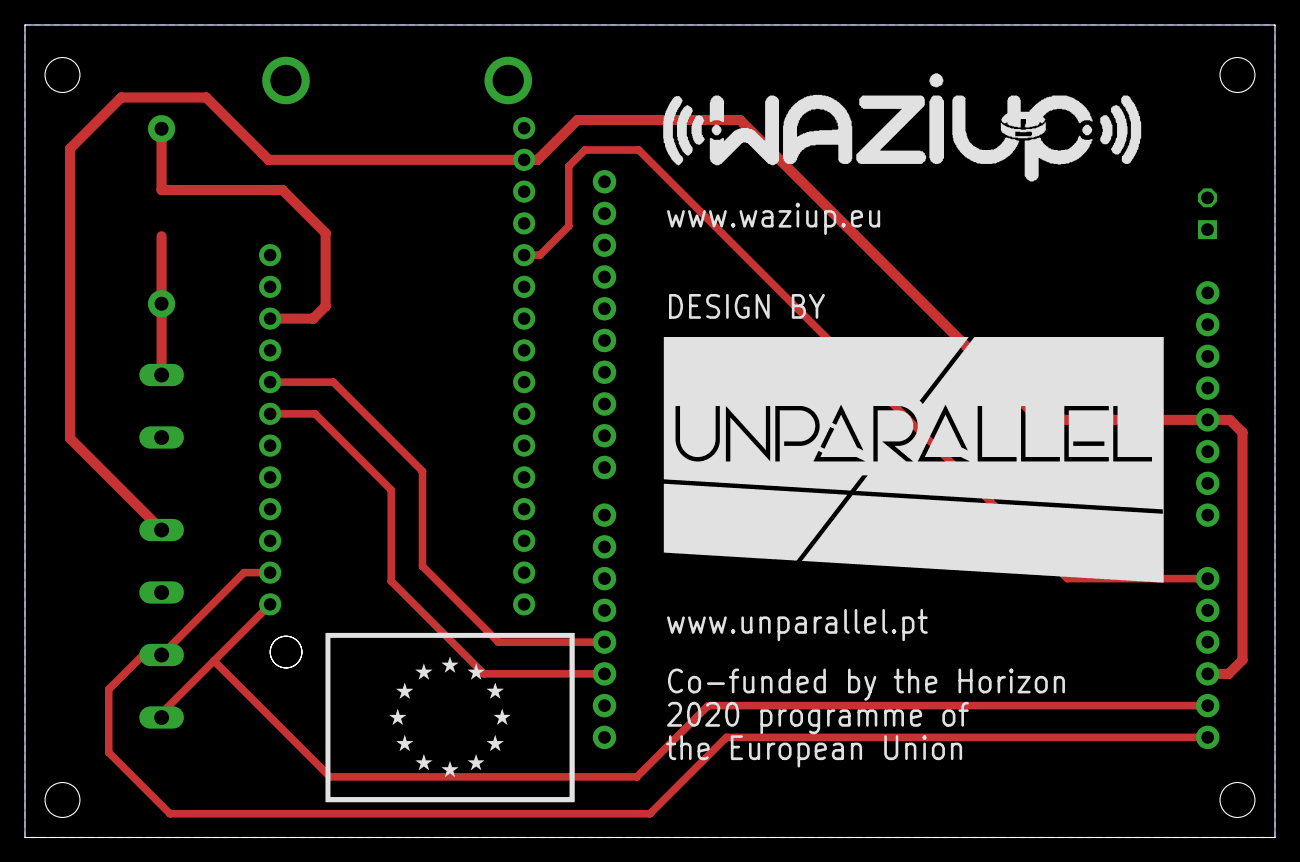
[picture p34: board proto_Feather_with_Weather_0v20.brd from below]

Board: 2 copper layers, 100.0 x 65.0 mm, 16 parts (3 on the bottom side), 9 nets.

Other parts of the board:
LOGO1: OSHW-LOGOM; OSHW-LOGO-M
STAND1, STAND2, STAND3, STAND4: MOUNTHOLE_110MIL
U$1: UNPARALLEL_LOGO_NEW_0_INVERT_BIG
U$2: FLAG_EU
U$3: LOGO_WAZIUP_4CM
U$4: UNPARALLEL_LOGO_NEW_0_INVERT_4CM

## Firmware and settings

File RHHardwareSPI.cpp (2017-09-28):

// RHHardwareSPI.h
// Author: Mike McCauley (mikem@airspayce.com)
// Copyright (C) 2011 Mike McCauley
// Contributed by Joanna Rutkowska
// $Id: RHHardwareSPI.cpp,v 1.15 2016/04/04 01:40:12 mikem Exp mikem $

#include "RHHardwareSPI.h"

// Declare a single default instance of the hardware SPI interface class
RHHardwareSPI hardware_spi;

#ifdef RH_HAVE_HARDWARE_SPI

#if (RH_PLATFORM == RH_PLATFORM_STM32) // Maple etc
// Declare an SPI interface to use
HardwareSPI SPI(1);
#elif (RH_PLATFORM == RH_PLATFORM_STM32STD) // STM32F4 Discovery
// Declare an SPI interface to use
HardwareSPI SPI(1);
#endif

// Arduino Due has default SPI pins on central SPI headers, and not on 10, 11, 12, 13
// as per other Arduinos
// http://21stdigitalhome.blogspot.com.au/2013/02/arduino-due-hardware-spi.html
#if defined (__arm__) && !defined(CORE_TEENSY) && !defined(SPI_CLOCK_DIV16)
 // Arduino Due in 1.5.5 has no definitions for SPI dividers
 // SPI clock divider is based on MCK of 84MHz  
 #define SPI_CLOCK_DIV16 (VARIANT_MCK/84000000) // 1MHz
 #define SPI_CLOCK_DIV8  (VARIANT_MCK/42000000) // 2MHz
 #define SPI_CLOCK_DIV4  (VARIANT_MCK/21000000) // 4MHz
 #define SPI_CLOCK_DIV2  (VARIANT_MCK/10500000) // 8MHz
 #define SPI_CLOCK_DIV1  (VARIANT_MCK/5250000)  // 16MHz
#endif

RHHardwareSPI::RHHardwareSPI(Frequency frequency, BitOrder bitOrder, DataMode dataMode)
    :
    RHGenericSPI(frequency, bitOrder, dataMode)
{
}

uint8_t RHHardwareSPI::transfer(uint8_t data) 
{
    return SPI.transfer(data);
}

void RHHardwareSPI::attachInterrupt() 
{
#if (RH_PLATFORM == RH_PLATFORM_ARDUINO)
    SPI.attachInterrupt();
#endif
}

void RHHardwareSPI::detachInterrupt() 
{
#if (RH_PLATFORM == RH_PLATFORM_ARDUINO)
    SPI.detachInterrupt();
#endif
}
    
void RHHardwareSPI::begin() 
{
    // Sigh: there are no common symbols for some of these SPI options across all platforms
#if (RH_PLATFORM == RH_PLATFORM_ARDUINO) || (RH_PLATFORM == RH_PLATFORM_UNO32) || (RH_PLATFORM == RH_PLATFORM_CHIPKIT_CORE)
    uint8_t dataMode;
    if (_dataMode == DataMode0)
	dataMode = SPI_MODE0;
    else if (_dataMode == DataMode1)
	dataMode = SPI_MODE1;
    else if (_dataMode == DataMode2)
	dataMode = SPI_MODE2;
    else if (_dataMode == DataMode3)
	dataMode = SPI_MODE3;
    else
	dataMode = SPI_MODE0;
#if (RH_PLATFORM == RH_PLATFORM_ARDUINO) && defined(__arm__) && defined(CORE_TEENSY)
    // Temporary work-around due to problem where avr_emulation.h does not work properly for the setDataMode() cal
    SPCR &= ~SPI_MODE_MASK;
#else
 #if (RH_PLATFORM == RH_PLATFORM_ARDUINO) && defined (__arm__) && defined(ARDUINO_ARCH_SAMD)
    // Zero requires begin() before anything else :-)
    SPI.begin();
 #endif

    SPI.setDataMode(dataMode);
#endif

#if (RH_PLATFORM == RH_PLATFORM_ARDUINO) && defined (__arm__) && (defined(ARDUINO_SAM_DUE) || defined(ARDUINO_ARCH_SAMD))
    // Arduino Due in 1.5.5 has its own BitOrder :-(
    // So too does Arduino Zero
    ::BitOrder bitOrder;
#else
    uint8_t bitOrder;
#endif
    if (_bitOrder == BitOrderLSBFirst)
	bitOrder = LSBFIRST;
    else
	bitOrder = MSBFIRST;
    SPI.setBitOrder(bitOrder);
    uint8_t divider;
    switch (_frequency)
    {
	case Frequency1MHz:
	default:
#if F_CPU == 8000000
	    divider = SPI_CLOCK_DIV8;
#else
	    divider = SPI_CLOCK_DIV16;
#endif
	    break;

	case Frequency2MHz:
#if F_CPU == 8000000
	    divider = SPI_CLOCK_DIV4;
#else
	    divider = SPI_CLOCK_DIV8;
#endif
	    break;

	case Frequency4MHz:
#if F_CPU == 8000000
	    divider = SPI_CLOCK_DIV2;
#else
	    divider = SPI_CLOCK_DIV4;
#endif
	    break;

	case Frequency8MHz:
	    divider = SPI_CLOCK_DIV2; // 4MHz on an 8MHz Arduino
	    break;

	case Frequency16MHz:
	    divider = SPI_CLOCK_DIV2; // Not really 16MHz, only 8MHz. 4MHz on an 8MHz Arduino
	    break;

    }

    SPI.setClockDivider(divider);
    SPI.begin();
    // Teensy requires it to be set _after_ begin()
    SPI.setClockDivider(divider);

#elif (RH_PLATFORM == RH_PLATFORM_STM32) // Maple etc
    spi_mode dataMode;
    // Hmmm, if we do this as a switch, GCC on maple gets v confused!
    if (_dataMode == DataMode0)
	dataMode = SPI_MODE_0;
    else if (_dataMode == DataMode1)
	dataMode = SPI_MODE_1;
    else if (_dataMode == DataMode2)
	dataMode = SPI_MODE_2;
    else if (_dataMode == DataMode3)
	dataMode = SPI_MODE_3;
    else
	dataMode = SPI_MODE_0;

    uint32 bitOrder;
    if (_bitOrder == BitOrderLSBFirst)
	bitOrder = LSBFIRST;
    else
	bitOrder = MSBFIRST;

    SPIFrequency frequency; // Yes, I know these are not exact equivalents.
    switch (_frequency)
    {
	case Frequency1MHz:
	default:
	    frequency = SPI_1_125MHZ;
	    break;

	case Frequency2MHz:
	    frequency = SPI_2_25MHZ;
	    break;

	case Frequency4MHz:
	    frequency = SPI_4_5MHZ;
	    break;

	case Frequency8MHz:
	    frequency = SPI_9MHZ;
	    break;

	case Frequency16MHz:
	    frequency = SPI_18MHZ;
	    break;

    }
    SPI.begin(frequency, bitOrder, dataMode);
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

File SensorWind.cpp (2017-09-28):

#include "SensorWind.h"


//Initialize
SensorWind::SensorWind(int interrupt_pin, double calibration, const uint8_t direction_pin)
{
	w_calibration=calibration;
	w_dir_pin=direction_pin;
	w_int_pin=interrupt_pin;
	wind=0;
	lastWindIRQ = millis();
	t_min=36000000;
	t_previous=0;
	t_interval=0;
	control=0;
}

	//---------------------------------------- Get Wind Speed --------------------------------------
	float SensorWind::getWindSpeed(long minutes)
	{
  		float windSpeed=0;

  		float period=0;

  		float deltaTime = (float)minutes*60;    // Convert minutes to seconds

	  	if (wind == 0)
	    	return 0;   // no interrupts return 0 kmh

		  if (deltaTime > 0)
	 	 	{
	  	  period = deltaTime/(float)wind;
	  	  windSpeed = 2.4 / period;
	 	 	}
	  	return (windSpeed);    // 1 interrupt = 2.4 kPh
	}
	//----------------------------------------------------------------------------------------------


	//---------------------------------- Increment Wind Direction Indice ---------------------------
	int SensorWind::incrementWindIndice()
	{
	  unsigned int indice=getWindIndice();

	  if (indice!=-1)
    		windPos[indice]++;  // Wind Direction (º)

      return indice;
	}
	//----------------------------------------------------------------------------------------------

	//-------------------------------- Returns the Wind Direction Indice ---------------------------
	int SensorWind::getWindIndice()
	{
	  // The following table is ADC readings for the wind direction sensor output, sorted from low to high.
	  // Each threshold is the midpoint between adjacent headings. The output is degrees for that ADC reading.
	  // Note that these are not in compass degree order! See Weather Meters datasheet for more information.

	  unsigned int adc = w_calibration*analogRead(w_dir_pin);

	  if (adc < 380) return (5);
	  if (adc < 393) return (3);
	  if (adc < 414) return (4);
	  if (adc < 456) return (7);
	  if (adc < 508) return (6);
	  if (adc < 551) return (9);
	  if (adc < 615) return (8);
	  if (adc < 680) return (1);
	  if (adc < 746) return (2);
	  if (adc < 801) return (11);
	  if (adc < 833) return (10);
	  if (adc < 878) return (15);
	  if (adc < 913) return (0);
	  if (adc < 940) return (13);
	  if (adc < 967) return (14);
	  if (adc < 990) return (12);
	  return (-1);
	}
	//----------------------------------------------------------------------------------------------


	//-------------------------------- Returns the Wind Direction Indice ---------------------------
	float SensorWind::getWindDirection()
	{
	  #ifdef DEBUG_UI
		  // For testing
		  Serial.println("");  Serial.println(" |||||| WIND POSICION |||||| ");
	  #endif

	  int count=0;
	  int indice=0;

	  // Get each minute wind direction
	  for (int i=0; i<16; i++)
	  {
	    if (windPos[i] > count)
	    {
	      count = windPos[i];
	      indice = i;
	    }

	    #ifdef DEBUG_UI
	    	// For testing
        Serial.print(" i: ");    Serial.print(i);    Serial.print(" - ");
        Serial.print(windPos[i]); Serial.println(" x");
      #endif
   	  }

   	  #ifdef DEBUG_UI
	  		// For testing
			  Serial.print("-- Angle occurencies in the last hour--: ");
			  Serial.print(" i: ");  Serial.print(indice);  Serial.print(" - ");
			  Serial.print(count); Serial.println("x");
	  #endif


    if (indice==5) return (112.5);
	  if (indice==3) return (67.5);
	  if (indice==4) return (90);
	  if (indice==7) return (157.5);
	  if (indice==6) return (135);
	  if (indice==9) return (202.5);
	  if (indice==8) return (180);
	  if (indice==1) return (22.5);
	  if (indice==2) return (45);
	  if (indice==11) return (247.5);
	  if (indice==10) return (225);
	  if (indice==15) return (337.5);
	  if (indice==0) return (0);
	  if (indice==13) return (292.5);
	  if (indice==14) return (315);
	  if (indice==12) return (270);
	  return (-1);    // error
	}
	//----------------------------------------------------------------------------------------------


	//------------------------------------ Returns the Wind Gust -----------------------------------
	float SensorWind::getWindGust()
	{
	  float windGust = 0;

	  if (t_min > 0)
	  {
	      float period = ((float)t_min/1000);    // Convert milliseconds to seconds
	      windGust=2.4/period;   // (1 interrupt/1 second) = 2.4kPh --> in 0.2 seconds --> (2.4/0.2)
	  }
	  return (windGust);
	}
	//----------------------------------------------------------------------------------------------

	//-------------------------------------	Get Wind Clicks ----------------------------------------
	long SensorWind::getWindClicks()
	{
		return wind;
	}
	//----------------------------------------------------------------------------------------------


	//-------------------------------	Get t_min between interrupts -------------------------------
	long SensorWind::getGustInterval()
	{
		return t_min;
	}
	//----------------------------------------------------------------------------------------------

	//-------------------------------- Wind Interrupt Routine --------------------------------------
	void SensorWind::ISR_WIND()
	{
		  // Ignore switch-bounce glitches less than 10ms (142MPH max reading) after the reed switch closes
		  if (millis() - lastWindIRQ > 10)
		  {
		    wind++;   // There is 1.492MPH for each click per second.
		    lastWindIRQ = millis();   // Grab the current time


		    // For each wind interrupt: get minimum time (in ms) between interrupts
		    t_interval=lastWindIRQ-t_previous;

		     // if is a new minimum time between interrups
		    if(t_interval<t_min)
		      t_min=t_interval;

		    t_previous=lastWindIRQ;
		  }
		  control=1;
	}
	//----------------------------------------------------------------------------------------------


	//--------------------------------- Attach Rain Interrupt --------------------------------------
	void SensorWind::attachWindInterrupt()
	{
		pinMode(w_int_pin, INPUT_PULLUP); // input from wind meters windspeed sensor
		attachInterrupt(digitalPinToInterrupt(w_int_pin), isr0, FALLING);    //FALLING
		SensorWind_instance = this;

	}
	//----------------------------------------------------------------------------------------------

	//----------------------------- Auxiliar Wind Interrupt ISR ------------------------------------
	void SensorWind::isr0()
	{
		SensorWind_instance->ISR_WIND();
	}
	//----------------------------------------------------------------------------------------------



	SensorWind * SensorWind::SensorWind_instance;		// Auxiliar instance to Rain Interrupt ISR




	//--------------------------- Clear the Wind Direction Indice vector ---------------------------
	void SensorWind::clearWind()
	{

	  	// Clear the Wind Direction Indice vector
		for (int i=0; i<16; i++)
  		{
      		windPos[i]=0;
 		}


		t_min=36000000;
  	wind=0;
  	control=0;					// (FINAL VERSION: TO BE DELETED)
	}
	//----------------------------------------------------------------------------------------------
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

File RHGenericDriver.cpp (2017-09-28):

// RHGenericDriver.cpp
//
// Copyright (C) 2014 Mike McCauley
// $Id: RHGenericDriver.cpp,v 1.19 2015/12/11 01:10:24 mikem Exp $

#include "RHGenericDriver.h"

RHGenericDriver::RHGenericDriver()
    :
    _mode(RHModeInitialising),
    _thisAddress(RH_BROADCAST_ADDRESS),
    _txHeaderTo(RH_BROADCAST_ADDRESS),
    _txHeaderFrom(RH_BROADCAST_ADDRESS),
    _txHeaderId(0),
    _txHeaderFlags(0),
    _rxBad(0),
    _rxGood(0),
    _txGood(0)
{
}

bool RHGenericDriver::init()
{
    return true;
}

// Blocks until a valid message is received
void RHGenericDriver::waitAvailable()
{
    while (!available())
	YIELD;
}

// Blocks until a valid message is received or timeout expires
// Return true if there is a message available
// Works correctly even on millis() rollover
bool RHGenericDriver::waitAvailableTimeout(uint16_t timeout)
{
    unsigned long starttime = millis();
    while ((millis() - starttime) < timeout)
    {
        if (available())
	{
           return true;
	}
	YIELD;
    }
    return false;
}

bool RHGenericDriver::waitPacketSent()
{
    while (_mode == RHModeTx)
	YIELD; // Wait for any previous transmit to finish
    return true;
}

bool RHGenericDriver::waitPacketSent(uint16_t timeout)
{
    unsigned long starttime = millis();
    while ((millis() - starttime) < timeout)
    {
        if (_mode != RHModeTx) // Any previous transmit finished?
           return true;
	YIELD;
    }
    return false;
}

void RHGenericDriver::setPromiscuous(bool promiscuous)
{
    _promiscuous = promiscuous;
}

void RHGenericDriver::setThisAddress(uint8_t address)
{
    _thisAddress = address;
}

void RHGenericDriver::setHeaderTo(uint8_t to)
{
    _txHeaderTo = to;
}

void RHGenericDriver::setHeaderFrom(uint8_t from)
{
    _txHeaderFrom = from;
}

void RHGenericDriver::setHeaderId(uint8_t id)
{
    _txHeaderId = id;
}

void RHGenericDriver::setHeaderFlags(uint8_t set, uint8_t clear)
{
    _txHeaderFlags &= ~clear;
    _txHeaderFlags |= set;
}

uint8_t RHGenericDriver::headerTo()
{
    return _rxHeaderTo;
}

uint8_t RHGenericDriver::headerFrom()
{
    return _rxHeaderFrom;
}

uint8_t RHGenericDriver::headerId()
{
    return _rxHeaderId;
}

uint8_t RHGenericDriver::headerFlags()
{
    return _rxHeaderFlags;
}

int8_t RHGenericDriver::lastRssi()
{
    return _lastRssi;
}

RHGenericDriver::RHMode  RHGenericDriver::mode()
{
    return _mode;
}

void  RHGenericDriver::setMode(RHMode mode)
{
    _mode = mode;
}

bool  RHGenericDriver::sleep()
{
    return false;
}

// Diagnostic help
void RHGenericDriver::printBuffer(const char* prompt, const uint8_t* buf, uint8_t len)
{
    uint8_t i;

#ifdef RH_HAVE_SERIAL
    Serial.println(prompt);
    for (i = 0; i < len; i++)
    {
	if (i % 16 == 15)
	    Serial.println(buf[i], HEX);
	else
	{
	    Serial.print(buf[i], HEX);
	    Serial.print(' ');
	}
    }
    Serial.println("");
#endif
}

uint16_t RHGenericDriver::rxBad()
{
    return _rxBad;
}

uint16_t RHGenericDriver::rxGood()
{
    return _rxGood;
}

uint16_t RHGenericDriver::txGood()
{
    return _txGood;
}

#if (RH_PLATFORM == RH_PLATFORM_ARDUINO) && defined(RH_PLATFORM_ATTINY)
// Tinycore does not have __cxa_pure_virtual, so without this we
// get linking complaints from the default code generated for pure virtual functions
extern "C" void __cxa_pure_virtual()
{
    while (1);
}
#endif

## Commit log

2017-02-21 Update
    Change the sleep time and the green led problem.
2017-04-07 Update
    ADC table values update
2017-09-28 ThingSpeak API
    Change the ThingSpeak channel id in the “LoRaWeatherStation.ino” example
2017-09-28 Time to run
    Added timeout in the “while(!Serial)”
2017-09-28 library.properties
    Update the version in the “library.properties” file
2017-09-29 Serial.prints update
    Update the Serial.prints messages
2018-04-12 Added PCB Board Schematics for Easy Assembly
    [proto_Feather_with_Weather_0v20.brd, proto_Feather_with_Weather_0v20.sch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]

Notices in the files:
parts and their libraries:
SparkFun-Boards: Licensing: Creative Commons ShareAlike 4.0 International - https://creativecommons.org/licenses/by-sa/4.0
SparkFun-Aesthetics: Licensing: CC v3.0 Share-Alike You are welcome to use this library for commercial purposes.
